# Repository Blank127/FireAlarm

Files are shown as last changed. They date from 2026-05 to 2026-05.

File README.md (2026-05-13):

# 🔥 Fire Alarm — Temperature Sensor Alarm System

> **CMPE2700 — PCB Design Project**
> STM32G0B1RETx · DS18B20 · DFRobot Gravity 7-Segment Displays · USB-C Powered

---

## Overview

A temperature monitoring and alarm system built on a custom PCB. The DS18B20 sensor continuously reads ambient temperature and displays it on a 4-digit 7-segment display. When the temperature exceeds a configurable threshold, an alarm LED activates. The alarm must be manually acknowledged by pressing the onboard button.

A second 7-segment display shows the current alarm threshold for reference at all times.

---

## Hardware

| Component | Description |
|---|---|
| **STM32G0B1RETx** | Main microcontroller |
| **DS18B20** | 1-Wire digital temperature sensor |
| **AMS1117-3.3** | LDO voltage regulator, steps down 5 V → 3.3 V |
| **DFRobot Gravity 4-Digit LED Display (×2)** | TM1650-based 7-segment displays over I2C |
| **USB-C Connector** | Board power input (5 V) |
| **SWD Header** | STM32 programming and debug interface |
| **Tactile Button** | Alarm acknowledge / reset |
| **External LED** | Alarm indicator |

---

## How It Works

1. The DS18B20 reads temperature every second over the 1-Wire bus
2. The current temperature is shown on **Display 1** (I2C1)
3. The alarm threshold is shown on **Display 2** (I2C2)
4. If the temperature exceeds the threshold, the **alarm LED turns on**
5. Press the **onboard button** to acknowledge and clear the alarm

---

## PCB

<!-- Replace the line below with your actual image once converted to PNG/JPG -->
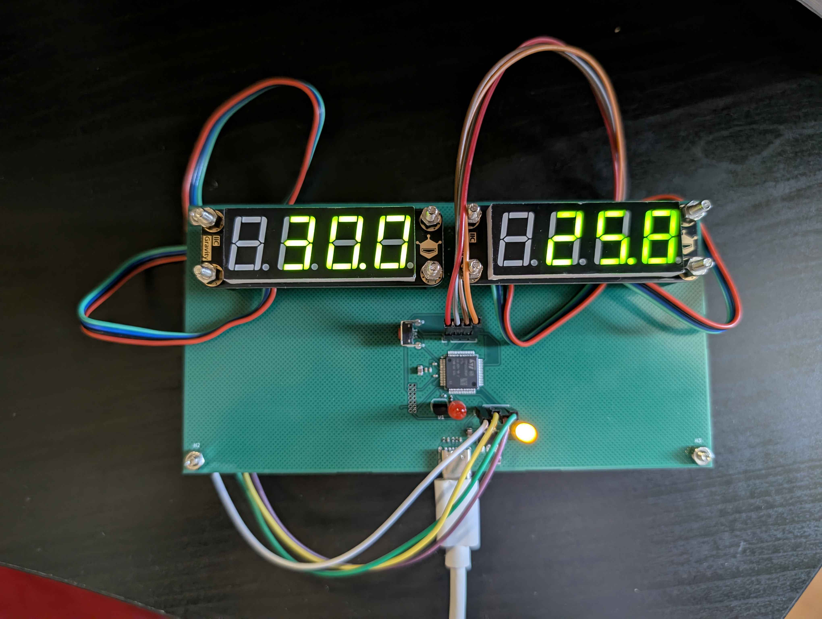
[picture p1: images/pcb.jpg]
PCB Photo


> 📷 *PCB photo — upload a JPG/PNG version of the image to add it here*

### Known Hardware Issue — J1 / J2 Header Pin Swap

> ⚠️ **Workaround required — jumper wires needed**

The I2C headers J1 and J2 were routed with the following pinout:

```
PCB Header (J1/J2):   5V · GND · SDA · SCL
```

However, the mating female connectors on the DFRobot Gravity displays use:

```
Display Connector:    5V · GND · SCL · SDA
```

The **SDA and SCL lines are swapped** between the PCB header and the display connector. As a result, the displays cannot be plugged in directly — they will not communicate.

**Fix:** Use jumper wires to cross SDA and SCL between the header and the display connector before plugging in.

This will be corrected in the next PCB revision by swapping the SDA/SCL positions on J1 and J2 in the schematic.

---

## Firmware

The firmware is written in C using the STM32 HAL library and structured across three STM32CubeIDE projects:

| Project | Description |
|---|---|
| `Temperature sensor/` | DS18B20 driver development and test |
| `SevenSeg/` | TM1650 7-segment display driver development and test |
| `Temperature alert system/` | Final integrated alarm application |

### Firmware Repository Structure

```
Firmware/
├── Temperature sensor/         # DS18B20 test project
├── SevenSeg/                   # 7-segment display test project
└── Temperature alert system/   # Final alarm application
Hardware/
├── PCB_Final.kicad_pcb         # PCB layout
├── PCB_Final.kicad_sch         # Schematic
└── PCB_Final.kicad_pro         # KiCad project file
```

---

## Programming the STM32

1. Connect an ST-Link programmer to the **SWD header** on the PCB
2. Power the board via **USB-C**
3. Open the project in **STM32CubeIDE**
4. Build and flash using **Run → Debug** or **Run → Run**

---

## Pin Assignments

| Signal | STM32 Pin | Notes |
|---|---|---|
| 1-Wire Data | PA (one_wire_data) | DS18B20 with 4.7 kΩ pull-up |
| I2C1 SDA/SCL | I2C1 | Display 1 — current temperature |
| I2C2 SDA/SCL | I2C2 | Display 2 — alarm threshold |
| Alarm LED | PA (ext_led) | Active high |
| Button (B1) | PC13 | Active low, internal pull-up |
| Green LED | PA5 | Onboard status/heartbeat |
| USART2 TX/RX | PA2 / PA3 | Debug output at 115200 baud |

---

## Author

**Aldrich Dias** — CMPE2750, 2026

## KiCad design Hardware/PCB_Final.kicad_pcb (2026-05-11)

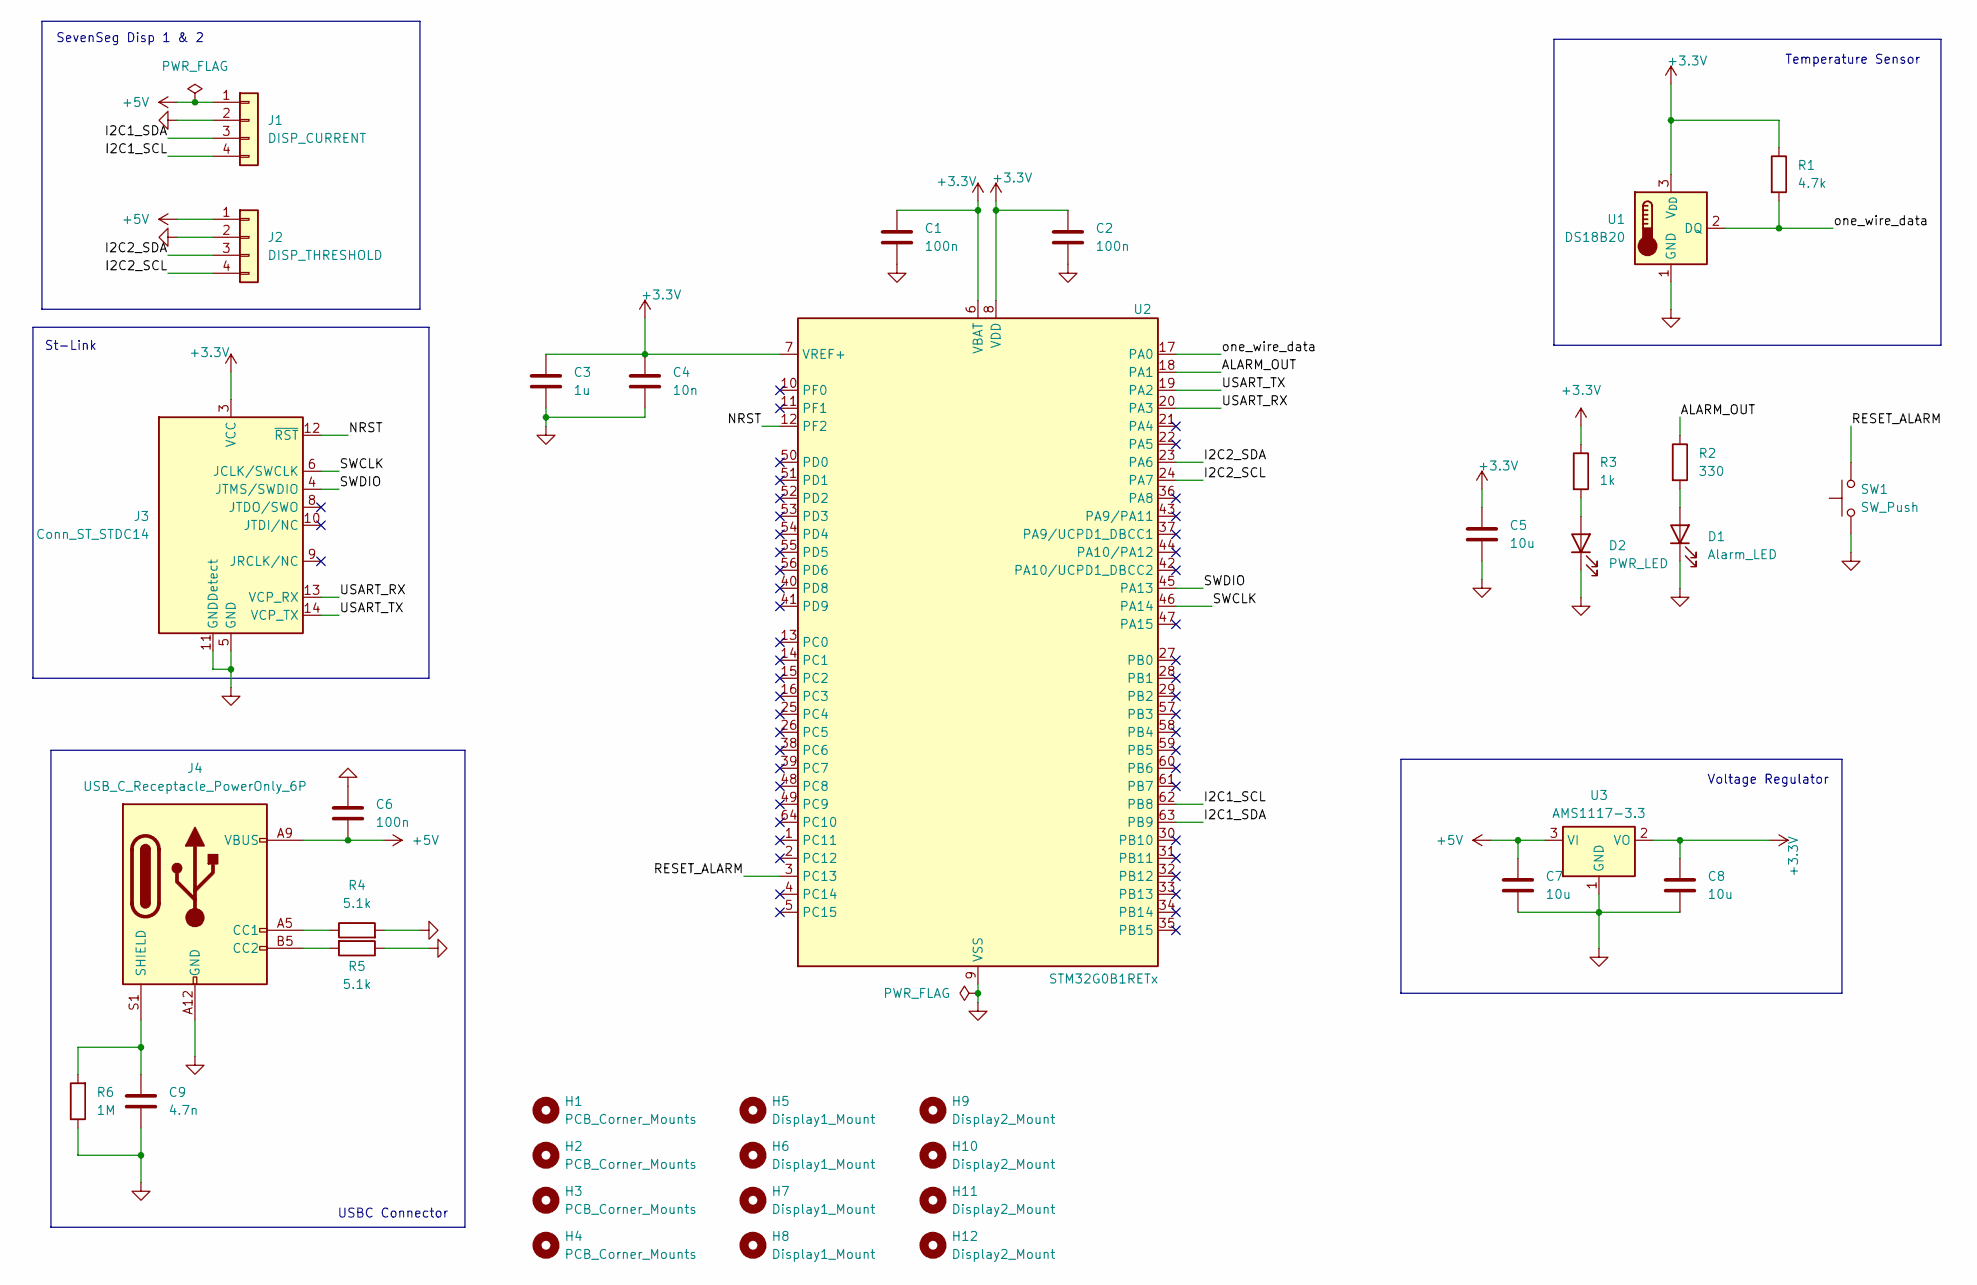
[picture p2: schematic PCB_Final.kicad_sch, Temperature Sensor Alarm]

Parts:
C1, C2, C6: 100n; C_0402_1005Metric
C3: 1u; C_0402_1005Metric
C4: 10n; C_0402_1005Metric
C5, C7, C8: 10u; C_0805_2012Metric
C9: 4.7n; C_0402_1005Metric
D1: Alarm_LED; LED_D3.0mm
D2: PWR_LED; LED_D3.0mm
H1, H2, H3, H4: PCB_Corner_Mounts; MountingHole_3.2mm_M3
H5, H6, H7, H8: Display1_Mount; MountingHole_3.2mm_M3
H9, H10, H11, H12: Display2_Mount; MountingHole_3.2mm_M3
J1: DISP_CURRENT; PinHeader_1x04_P2.54mm_Vertical
J2: DISP_THRESHOLD; PinHeader_1x04_P2.54mm_Vertical
J3: Conn_ST_STDC14; PinHeader_2x07_P1.27mm_Vertical
J4: USB_C_Receptacle_PowerOnly_6P; USB_C_Receptacle_GCT_USB4125-xx-x-0190_6P_TopMnt_Horizontal
R1: 4.7k; R_0402_1005Metric
R2: 330; R_0402_1005Metric
R3: 1k; R_0402_1005Metric
R4, R5: 5.1k; R_0402_1005Metric
R6: 1M; R_0402_1005Metric
SW1: SW_Push; SW_Tactile_SPST_Angled_PTS645Vx31-2LFS
U1: DS18B20; TO-92_Inline
U2: STM32G0B1RETx; LQFP-64_10x10mm_P0.5mm
U3: AMS1117-3.3; SOT-223-3_TabPin2

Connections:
+3.3V: C1.1, C2.1, C3.1, C4.1, C5.1, C8.1, J3.3 (VCC), R1.1, R3.1, U1.3 (V_{DD}), U2.6 (VBAT), U2.7 (VREF+), U2.8 (VDD), U3.2 (VO)
+5V: C6.2, C7.1, J1.1, J2.1, J4.A9 (VBUS), J4.B9 (VBUS), U3.3 (VI)
/ALARM_OUT: R2.1, U2.18 (PA1)
/I2C1_SCL: J1.4, U2.62 (PB8)
/I2C1_SDA: J1.3, U2.63 (PB9)
/I2C2_SCL: J2.4, U2.24 (PA7)
/I2C2_SDA: J2.3, U2.23 (PA6)
/NRST: J3.12 (~RST), U2.12 (PF2)
/RESET_ALARM: SW1.2, U2.3 (PC13)
/SWCLK: J3.6 (JCLK/SWCLK), U2.46 (PA14)
/SWDIO: J3.4 (JTMS/SWDIO), U2.45 (PA13)
/USART_RX: J3.13 (VCP_RX), U2.20 (PA3)
/USART_TX: J3.14 (VCP_TX), U2.19 (PA2)
/one_wire_data: R1.2, U1.2 (DQ), U2.17 (PA0)
GND: C1.2, C2.2, C3.2, C4.2, C5.2, C6.1, C7.2, C8.2, C9.2, D1.1 (K), D2.1 (K), J1.2, J2.2, J3.5 (GND), J3.7 (GND), J3.11 (GNDDetect), J4.A12 (GND), J4.B12 (GND), R4.2, R5.1, R6.1, SW1.1, U1.1 (GND), U2.9 (VSS), U3.1 (GND)
unnamed: D1.2 (A), R2.2
unnamed: D2.2 (A), R3.2
unnamed: J4.A5 (CC1), R4.1
unnamed: J4.B5 (CC2), R5.2
unnamed: C9.1, J4.S1 (SHIELD), R6.2

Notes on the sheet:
St-Link
USBC Connector
Temperature Sensor
Voltage Regulator
SevenSeg Disp 1 & 2

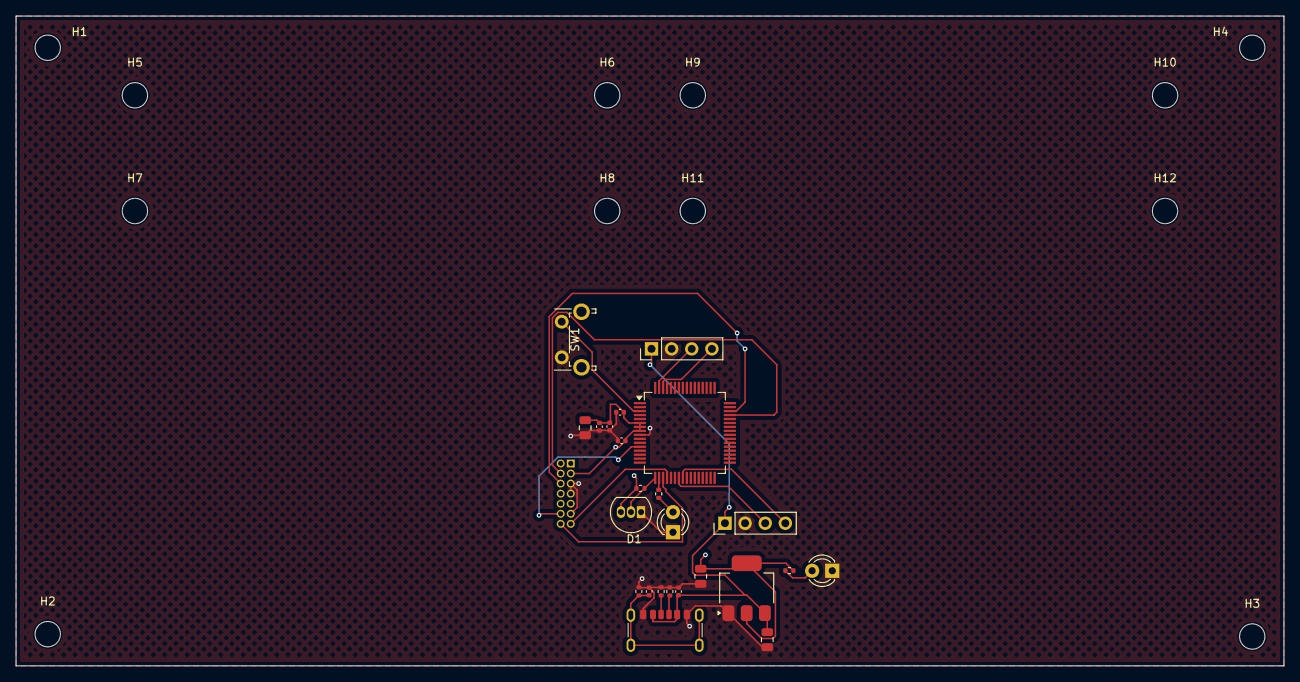
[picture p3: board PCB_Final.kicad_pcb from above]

Board: 4 copper layers, 160.0 x 82.0 mm, 37 parts (1 on the bottom side), 20 nets.

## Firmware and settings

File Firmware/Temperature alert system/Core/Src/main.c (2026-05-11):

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

/* Includes ------------------------------------------------------------------*/
#include "main.h"

/* USER CODE BEGIN Includes */
#include "ds18b20.h"
#include "seven_seg.h"
#include <math.h>
/* USER CODE END Includes */

/* USER CODE BEGIN PTD */

/**
 * @brief Alarm state.
 */
typedef enum
{
    ALARM_STATE_OFF,  /**< Alarm inactive — temperature below threshold */
    ALARM_STATE_ON    /**< Alarm active   — temperature exceeded threshold */
} AlarmState_t;

/* USER CODE END PTD */

/* USER CODE BEGIN PD */

#define THRESHOLD_TEMP          30.0f   /**< Default alarm threshold in degrees Celsius */
#define TEMP_SAMPLE_PERIOD_MS   1000    /**< Total loop period in ms (conversion + idle) */

/* USER CODE END PD */

I2C_HandleTypeDef hi2c1;
I2C_HandleTypeDef hi2c2;

TIM_HandleTypeDef htim2;

UART_HandleTypeDef huart2;

/* USER CODE BEGIN PV */

SevenSeg_Handle_t display_current;    /**< Display handle for current temperature (I2C1) */
SevenSeg_Handle_t display_threshold;  /**< Display handle for alarm threshold     (I2C2) */

float temp_current  = 0.0f;            /**< Most recent valid temperature reading in °C  */
float temp_threshold = THRESHOLD_TEMP; /**< Active alarm threshold in °C                 */
AlarmState_t alarm_state = ALARM_STATE_OFF; /**< Current alarm state                     */

volatile bool button_pressed = false;  /**< Set by EXTI ISR; cleared in main loop        */

/* USER CODE END PV */

void SystemClock_Config(void);
static void MX_GPIO_Init(void);
static void MX_USART2_UART_Init(void);
static void MX_I2C1_Init(void);
static void MX_I2C2_Init(void);
static void MX_TIM2_Init(void);
/* USER CODE BEGIN PFP */

static void LED_SetState(bool on);
static void DisplayTemperature(SevenSeg_Handle_t *display, float temp);

/* USER CODE END PFP */

/* USER CODE BEGIN 0 */

/**
 * @brief  Drive the external alarm LED on or off.
 * @param  on  true to illuminate the LED, false to extinguish it.
 */
static void LED_SetState(bool on)
{
    if (on)
    {
        HAL_GPIO_WritePin(ext_led_GPIO_Port, ext_led_Pin, GPIO_PIN_SET);
    }
    else
    {
        HAL_GPIO_WritePin(ext_led_GPIO_Port, ext_led_Pin, GPIO_PIN_RESET);
    }
}

/**
 * @brief  Format a float temperature value and write it to a 7-segment display.
 *
 * Multiplies @p temp by 10, rounds to the nearest integer, and calls
 * SevenSeg_DisplayDecimal() to show one decimal place (e.g. 25.3 °C → "25.3").
 *
 * @param  display  Pointer to an initialised SevenSeg_Handle_t.
 * @param  temp     Temperature in degrees Celsius.
 */
static void DisplayTemperature(SevenSeg_Handle_t *display, float temp)
{
    uint16_t value = (uint16_t)roundf(temp * 10.0f);
    SevenSeg_DisplayDecimal(display, value);
}

/* USER CODE END 0 */

/**
 * @brief  Application entry point.
 * @retval int  Never returns.
 */
int main(void)
{

  /* MCU Configuration--------------------------------------------------------*/

  /* Reset of all peripherals, Initializes the Flash interface and the Systick. */
  HAL_Init();

  /* Configure the system clock */
  SystemClock_Config();

  /* Initialize all configured peripherals */
  MX_GPIO_Init();
  MX_USART2_UART_Init();
  MX_I2C1_Init();
  MX_I2C2_Init();
  MX_TIM2_Init();
  /* USER CODE BEGIN 2 */

  /* Start TIM2 as a free-running microsecond counter for the DS18B20 1-Wire driver */
  HAL_TIM_Base_Start(&htim2);

  /* Initialise DS18B20 — halt on failure (sensor required for operation) */
  if (!DS18B20_Init())
  {
      Error_Handler();
  }

  /* Initialise current temperature display on I2C1 */
  if (SevenSeg_Init(&display_current, &hi2c1) != SEVEN_SEG_OK)
  {
      Error_Handler();
  }

  /* Initialise threshold display on I2C2 */
  if (SevenSeg_Init(&display_threshold, &hi2c2) != SEVEN_SEG_OK)
  {
      Error_Handler();
  }

  /* Show the default threshold on startup */
  DisplayTemperature(&display_threshold, temp_threshold);

  /* USER CODE END 2 */

  /* Infinite loop */
  /* USER CODE BEGIN WHILE */
  while (1)
  {
      /* ----------------------------------------------------------------
       * Button handling — acknowledge alarm on B1 press
       * button_pressed is set by the EXTI ISR (HAL_GPIO_EXTI_Falling_Callback)
       * ---------------------------------------------------------------- */
      if (button_pressed)
      {
          button_pressed = false;  /* Clear ISR flag */

          /* Debounce delay */
          HAL_Delay(50);

          /* Confirm button is still held (active low) */
          if (HAL_GPIO_ReadPin(B1_GPIO_Port, B1_Pin) == GPIO_PIN_RESET)
          {
              /* Acknowledge alarm — turn off LED and return to idle state */
              if (alarm_state == ALARM_STATE_ON)
              {
                  alarm_state = ALARM_STATE_OFF;
                  LED_SetState(false);
              }
          }
      }

      /* ----------------------------------------------------------------
       * Temperature measurement
       * ---------------------------------------------------------------- */

      /* Trigger conversion and wait for 12-bit result (max 750 ms) */
      DS18B20_StartConversion();
      HAL_Delay(750);

      float temp_new = DS18B20_ReadTemperature();

      /* Accept only readings within the DS18B20 valid range (-55 to +125 °C) */
      if (temp_new > -100.0f && temp_new < 125.0f)
      {
          temp_current = temp_new;

          /* Refresh the current temperature display */
          DisplayTemperature(&display_current, temp_current);

          /* Trigger alarm if threshold is exceeded and alarm is not already active */
          if (alarm_state == ALARM_STATE_OFF)
          {
              if (temp_current > temp_threshold)
              {
                  alarm_state = ALARM_STATE_ON;
                  LED_SetState(true);
              }
          }
      }

      /* Idle for the remainder of the sample period */
      HAL_Delay(TEMP_SAMPLE_PERIOD_MS - 750);

    /* USER CODE END WHILE */

    /* USER CODE BEGIN 3 */
  }
  /* USER CODE END 3 */
}

/**
 * @brief  Configure system clocks.
 *
 * Source: HSI @ 16 MHz, no PLL. SYSCLK / HCLK / PCLK1 all at 16 MHz,
 * flash latency 0.
 *
 * @retval None
 */
void SystemClock_Config(void)
{
  RCC_OscInitTypeDef RCC_OscInitStruct = {0};
  RCC_ClkInitTypeDef RCC_ClkInitStruct = {0};

  /** Configure the main internal regulator output voltage
  */
  HAL_PWREx_ControlVoltageScaling(PWR_REGULATOR_VOLTAGE_SCALE1);

  /** Initializes the RCC Oscillators according to the specified parameters
  * in the RCC_OscInitTypeDef structure.
  */
  RCC_OscInitStruct.OscillatorType = RCC_OSCILLATORTYPE_HSI;
  RCC_OscInitStruct.HSIState = RCC_HSI_ON;
  RCC_OscInitStruct.HSIDiv = RCC_HSI_DIV1;
  RCC_OscInitStruct.HSICalibrationValue = RCC_HSICALIBRATION_DEFAULT;
  RCC_OscInitStruct.PLL.PLLState = RCC_PLL_NONE;
  if (HAL_RCC_OscConfig(&RCC_OscInitStruct) != HAL_OK)
  {
    Error_Handler();
  }

  /** Initializes the CPU, AHB and APB buses clocks
  */
  RCC_ClkInitStruct.ClockType = RCC_CLOCKTYPE_HCLK|RCC_CLOCKTYPE_SYSCLK
                              |RCC_CLOCKTYPE_PCLK1;
  RCC_ClkInitStruct.SYSCLKSource = RCC_SYSCLKSOURCE_HSI;
  RCC_ClkInitStruct.AHBCLKDivider = RCC_SYSCLK_DIV1;
  RCC_ClkInitStruct.APB1CLKDivider = RCC_HCLK_DIV1;

  if (HAL_RCC_ClockConfig(&RCC_ClkInitStruct, FLASH_LATENCY_0) != HAL_OK)
  {
    Error_Handler();
  }
}

/**
 * @brief  Initialise I2C1.
 *
 * Timing register 0x00300617 targets ~100 kHz standard mode on a 16 MHz HSI
 * clock. Analogue filter enabled, digital filter off.
 *
 * @retval None
 */
static void MX_I2C1_Init(void)
{

  hi2c1.Instance = I2C1;
  hi2c1.Init.Timing = 0x00300617;
  hi2c1.Init.OwnAddress1 = 0;
  hi2c1.Init.AddressingMode = I2C_ADDRESSINGMODE_7BIT;
  hi2c1.Init.DualAddressMode = I2C_DUALADDRESS_DISABLE;
  hi2c1.Init.OwnAddress2 = 0;
  hi2c1.Init.OwnAddress2Masks = I2C_OA2_NOMASK;
  hi2c1.Init.GeneralCallMode = I2C_GENERALCALL_DISABLE;
  hi2c1.Init.NoStretchMode = I2C_NOSTRETCH_DISABLE;
  if (HAL_I2C_Init(&hi2c1) != HAL_OK)
  {
    Error_Handler();
  }

  /** Configure Analogue filter
  */
  if (HAL_I2CEx_ConfigAnalogFilter(&hi2c1, I2C_ANALOGFILTER_ENABLE) != HAL_OK)
  {
    Error_Handler();
  }

  /** Configure Digital filter
  */
  if (HAL_I2CEx_ConfigDigitalFilter(&hi2c1, 0) != HAL_OK)
  {
    Error_Handler();
  }
}

/**
 * @brief  Initialise I2C2.
 *
 * Identical configuration to I2C1 — same timing, analogue filter enabled,
 * digital filter off.
 *
 * @retval None
 */
static void MX_I2C2_Init(void)
{

  hi2c2.Instance = I2C2;
  hi2c2.Init.Timing = 0x00300617;
  hi2c2.Init.OwnAddress1 = 0;
  hi2c2.Init.AddressingMode = I2C_ADDRESSINGMODE_7BIT;
  hi2c2.Init.DualAddressMode = I2C_DUALADDRESS_DISABLE;
  hi2c2.Init.OwnAddress2 = 0;
  hi2c2.Init.OwnAddress2Masks = I2C_OA2_NOMASK;
  hi2c2.Init.GeneralCallMode = I2C_GENERALCALL_DISABLE;
  hi2c2.Init.NoStretchMode = I2C_NOSTRETCH_DISABLE;
  if (HAL_I2C_Init(&hi2c2) != HAL_OK)
  {
    Error_Handler();
  }

  /** Configure Analogue filter
  */
  if (HAL_I2CEx_ConfigAnalogFilter(&hi2c2, I2C_ANALOGFILTER_ENABLE) != HAL_OK)
  {
    Error_Handler();
  }

  /** Configure Digital filter
  */
  if (HAL_I2CEx_ConfigDigitalFilter(&hi2c2, 0) != HAL_OK)
  {
    Error_Handler();
  }
}

/**
 * @brief  Initialise TIM2 as a free-running microsecond counter.
 *
 * Prescaler of 15 on a 16 MHz HSI clock gives a 1 MHz tick (1 µs resolution).
 * Period set to 65535 (max 16-bit). Used exclusively by the DS18B20 1-Wire driver.
 *
 * @retval None
 */
static void MX_TIM2_Init(void)
{

  TIM_ClockConfigTypeDef sClockSourceConfig = {0};
  TIM_MasterConfigTypeDef sMasterConfig = {0};

  htim2.Instance = TIM2;
  htim2.Init.Prescaler = 15;
  htim2.Init.CounterMode = TIM_COUNTERMODE_UP;
  htim2.Init.Period = 65535;
  htim2.Init.ClockDivision = TIM_CLOCKDIVISION_DIV1;
  htim2.Init.AutoReloadPreload = TIM_AUTORELOAD_PRELOAD_ENABLE;
  if (HAL_TIM_Base_Init(&htim2) != HAL_OK)
  {
    Error_Handler();
  }
  sClockSourceConfig.ClockSource = TIM_CLOCKSOURCE_INTERNAL;
  if (HAL_TIM_ConfigClockSource(&htim2, &sClockSourceConfig) != HAL_OK)
  {
    Error_Handler();
  }
  sMasterConfig.MasterOutputTrigger = TIM_TRGO_RESET;
  sMasterConfig.MasterSlaveMode = TIM_MASTERSLAVEMODE_DISABLE;
  if (HAL_TIMEx_MasterConfigSynchronization(&htim2, &sMasterConfig) != HAL_OK)
  {
    Error_Handler();
  }
}

/**
 * @brief  Initialise USART2 — 115200 8N1, no hardware flow control, FIFO off.
 * @retval None
 */
static void MX_USART2_UART_Init(void)
{

  huart2.Instance = USART2;
  huart2.Init.BaudRate = 115200;
  huart2.Init.WordLength = UART_WORDLENGTH_8B;
  huart2.Init.StopBits = UART_STOPBITS_1;
  huart2.Init.Parity = UART_PARITY_NONE;
  huart2.Init.Mode = UART_MODE_TX_RX;
  huart2.Init.HwFlowCtl = UART_HWCONTROL_NONE;
  huart2.Init.OverSampling = UART_OVERSAMPLING_16;
  huart2.Init.OneBitSampling = UART_ONE_BIT_SAMPLE_DISABLE;
  huart2.Init.ClockPrescaler = UART_PRESCALER_DIV1;
  huart2.AdvancedInit.AdvFeatureInit = UART_ADVFEATURE_NO_INIT;
  if (HAL_UART_Init(&huart2) != HAL_OK)
  {
    Error_Handler();
  }
  if (HAL_UARTEx_SetTxFifoThreshold(&huart2, UART_TXFIFO_THRESHOLD_1_8) != HAL_OK)
  {
    Error_Handler();
  }
  if (HAL_UARTEx_SetRxFifoThreshold(&huart2, UART_RXFIFO_THRESHOLD_1_8) != HAL_OK)
  {
    Error_Handler();
  }
  if (HAL_UARTEx_DisableFifoMode(&huart2) != HAL_OK)
  {
    Error_Handler();
  }
}

/**
 * @brief  Initialise GPIO pins.
 *
 * - B1            (PC13): input, falling-edge EXTI, internal pull-up (alarm acknowledge).
 * - one_wire_data (PA):   open-drain output, low speed (DS18B20 1-Wire bus).
 * - ext_led       (PA):   push-pull output, low speed, pull-up (external alarm LED).
 * - LED_GREEN     (PA5):  push-pull output, high speed (onboard status LED).
 *
 * EXTI4_15 interrupt enabled at priority 0 for the B1 button.
 *
 * @retval None
 */
static void MX_GPIO_Init(void)
{
  GPIO_InitTypeDef GPIO_InitStruct = {0};
  /* GPIO Ports Clock Enable */
  __HAL_RCC_GPIOC_CLK_ENABLE();
  __HAL_RCC_GPIOF_CLK_ENABLE();
  __HAL_RCC_GPIOA_CLK_ENABLE();
  __HAL_RCC_GPIOB_CLK_ENABLE();

  /*Configure GPIO pin Output Level */
  HAL_GPIO_WritePin(GPIOA, one_wire_data_Pin|ext_led_Pin|LED_GREEN_Pin, GPIO_PIN_RESET);

  /*Configure GPIO pin : B1_Pin */
  GPIO_InitStruct.Pin = B1_Pin;
  GPIO_InitStruct.Mode = GPIO_MODE_IT_FALLING;
  GPIO_InitStruct.Pull = GPIO_PULLUP;
  HAL_GPIO_Init(B1_GPIO_Port, &GPIO_InitStruct);

  /*Configure GPIO pin : one_wire_data_Pin */
  GPIO_InitStruct.Pin = one_wire_data_Pin;
  GPIO_InitStruct.Mode = GPIO_MODE_OUTPUT_OD;
  GPIO_InitStruct.Pull = GPIO_NOPULL;
  GPIO_InitStruct.Speed = GPIO_SPEED_FREQ_LOW;
  HAL_GPIO_Init(one_wire_data_GPIO_Port, &GPIO_InitStruct);

  /*Configure GPIO pin : ext_led_Pin */
  GPIO_InitStruct.Pin = ext_led_Pin;
  GPIO_InitStruct.Mode = GPIO_MODE_OUTPUT_PP;
  GPIO_InitStruct.Pull = GPIO_PULLUP;
  GPIO_InitStruct.Speed = GPIO_SPEED_FREQ_LOW;
  HAL_GPIO_Init(ext_led_GPIO_Port, &GPIO_InitStruct);

  /*Configure GPIO pin : LED_GREEN_Pin */
  GPIO_InitStruct.Pin = LED_GREEN_Pin;
  GPIO_InitStruct.Mode = GPIO_MODE_OUTPUT_PP;
  GPIO_InitStruct.Pull = GPIO_NOPULL;
  GPIO_InitStruct.Speed = GPIO_SPEED_FREQ_HIGH;
  HAL_GPIO_Init(LED_GREEN_GPIO_Port, &GPIO_InitStruct);

  /* EXTI interrupt init*/
  HAL_NVIC_SetPriority(EXTI4_15_IRQn, 0, 0);
  HAL_NVIC_EnableIRQ(EXTI4_15_IRQn);

}

/* USER CODE BEGIN 4 */

/**
 * @brief  EXTI falling-edge callback — handles B1 button press.
 *
 * Sets the @c button_pressed flag for processing in the main loop.
 * HAL_Delay must not be called from within an ISR context.
 *
 * @param  GPIO_Pin  Pin that triggered the interrupt.
 */
void HAL_GPIO_EXTI_Falling_Callback(uint16_t GPIO_Pin)
{
    if (GPIO_Pin == B1_Pin)
    {
        button_pressed = true;
    }
}

/* USER CODE END 4 */

/**
 * @brief  Fatal error handler — disables interrupts and halts.
 *
 * Called by HAL on any peripheral initialisation failure. Extend this
 * function to add LED blink patterns or UART fault reporting if needed.
 *
 * @retval None
 */
void Error_Handler(void)
{
  /* USER CODE BEGIN Error_Handler_Debug */
  __disable_irq();
  while (1)
  {
  }
  /* USER CODE END Error_Handler_Debug */
}

#ifdef  USE_FULL_ASSERT
/**
 * @brief  assert_param failure callback.
 * @param  file  Source file where the assertion failed.
 * @param  line  Line number of the failed assertion.
 * @retval None
 */
void assert_failed(uint8_t *file, uint32_t line)
{
  /* USER CODE BEGIN 6 */
  /* User can add their own implementation to report the file name and line number,
     e.g.: printf("Wrong parameters value: file %s on line %d\r\n", file, line) */
  /* USER CODE END 6 */
}
#endif /* USE_FULL_ASSERT */

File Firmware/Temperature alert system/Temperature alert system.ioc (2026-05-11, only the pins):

Mcu.UserName=STM32G0B1RETx
PA0.GPIO_Label=one_wire_data
PA0.Signal=GPIO_Output
PA1.GPIO_Label=ext_led
PA1.Signal=GPIO_Output
PA13.GPIO_Label=TMS
PA13.Signal=SYS_SWDIO
PA14-BOOT0.GPIO_Label=TCK
PA14-BOOT0.Signal=SYS_SWCLK
PA2.GPIO_Label=USART2_TX [STLK_TX]
PA2.Signal=USART2_TX
PA3.GPIO_Label=USART2_RX [STLK_RX]
PA3.Signal=USART2_RX
PA5.GPIO_Label=LED_GREEN
PA5.Signal=GPIO_Output
PA6.Signal=I2C2_SDA
PA7.Signal=I2C2_SCL
PB8.Signal=I2C1_SCL
PB9.Signal=I2C1_SDA
PC13.GPIO_Label=B1 [blue push button]
PC13.Signal=GPXTI13

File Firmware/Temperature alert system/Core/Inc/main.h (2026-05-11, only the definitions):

#define B1_Pin GPIO_PIN_13
#define B1_GPIO_Port GPIOC
#define B1_EXTI_IRQn EXTI4_15_IRQn
#define MCO_Pin GPIO_PIN_0
#define MCO_GPIO_Port GPIOF
#define one_wire_data_Pin GPIO_PIN_0
#define one_wire_data_GPIO_Port GPIOA
#define ext_led_Pin GPIO_PIN_1
#define ext_led_GPIO_Port GPIOA
#define USART2_TX_Pin GPIO_PIN_2
#define USART2_TX_GPIO_Port GPIOA
#define USART2_RX_Pin GPIO_PIN_3
#define USART2_RX_GPIO_Port GPIOA
#define LED_GREEN_Pin GPIO_PIN_5
#define LED_GREEN_GPIO_Port GPIOA
#define TMS_Pin GPIO_PIN_13
#define TMS_GPIO_Port GPIOA
#define TCK_Pin GPIO_PIN_14
#define TCK_GPIO_Port GPIOA

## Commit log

2026-05-11 Add three STM32 firmware projects
    Import initial STM32CubeIDE firmware for three projects: SevenSeg, Temperature sensor, and Temperature alert system. Adds project metadata (.project, .cproject, .mxproject, .ioc) plus Core and Startu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
2026-05-11 Add KiCad final PCB, schematic and project
    Add complete KiCad project files for the final PCB: Hardware/PCB_Final.kicad_pcb, Hardware/PCB_Final.kicad_sch and Hardware/PCB_Final.kicad_pro. Includes KiCad 9 board file with layer stackup, nets (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
    [PCB_Final.kicad_pcb, PCB_Final.kicad_sch]
2026-05-12 Use Markdown image in README and update PCB photo
    Replace the HTML <img> tag in README.md with a Markdown image reference for the PCB photo and remove the inline rotate(180deg) style so the image displays normally. The binary images/pcb.jpg was also updated (new or re-encoded photo) to reflect the uploaded image.

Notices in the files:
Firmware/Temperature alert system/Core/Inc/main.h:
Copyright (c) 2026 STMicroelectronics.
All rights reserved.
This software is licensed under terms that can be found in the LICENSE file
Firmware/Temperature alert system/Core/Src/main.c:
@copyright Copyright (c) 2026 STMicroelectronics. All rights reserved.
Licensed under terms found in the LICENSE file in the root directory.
